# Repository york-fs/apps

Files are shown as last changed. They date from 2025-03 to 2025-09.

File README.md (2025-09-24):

# Accelerator Pedal Position Sensor (APPS)

A custom accelerator pedal position sensor built around an STM32F103 MCU for drive-by-wire and EV applications.  
This module measures pedal position using two SS49E Hall-effect sensors with independent, opposed magnets, provides a digital brake signal, and communicates throttle data directly to the inverter over CAN bus.

## Features
- **MCU**: STM32F103
- **Position sensing**:  
  - Two SS49E Hall-effect sensors  
  - Independent, opposed magnet configuration for rule compliance and redundancy 
- **Brake output**: Digital output line for brake LED / ECU input  
- **User controls**:  
  - Reset button  
  - Calibration button (pedal travel limits)
- **CAN transceiver**:  
  - Throttle data transmission  
  - Ready-to-drive state reporting  
  - Calibration / curve configuration



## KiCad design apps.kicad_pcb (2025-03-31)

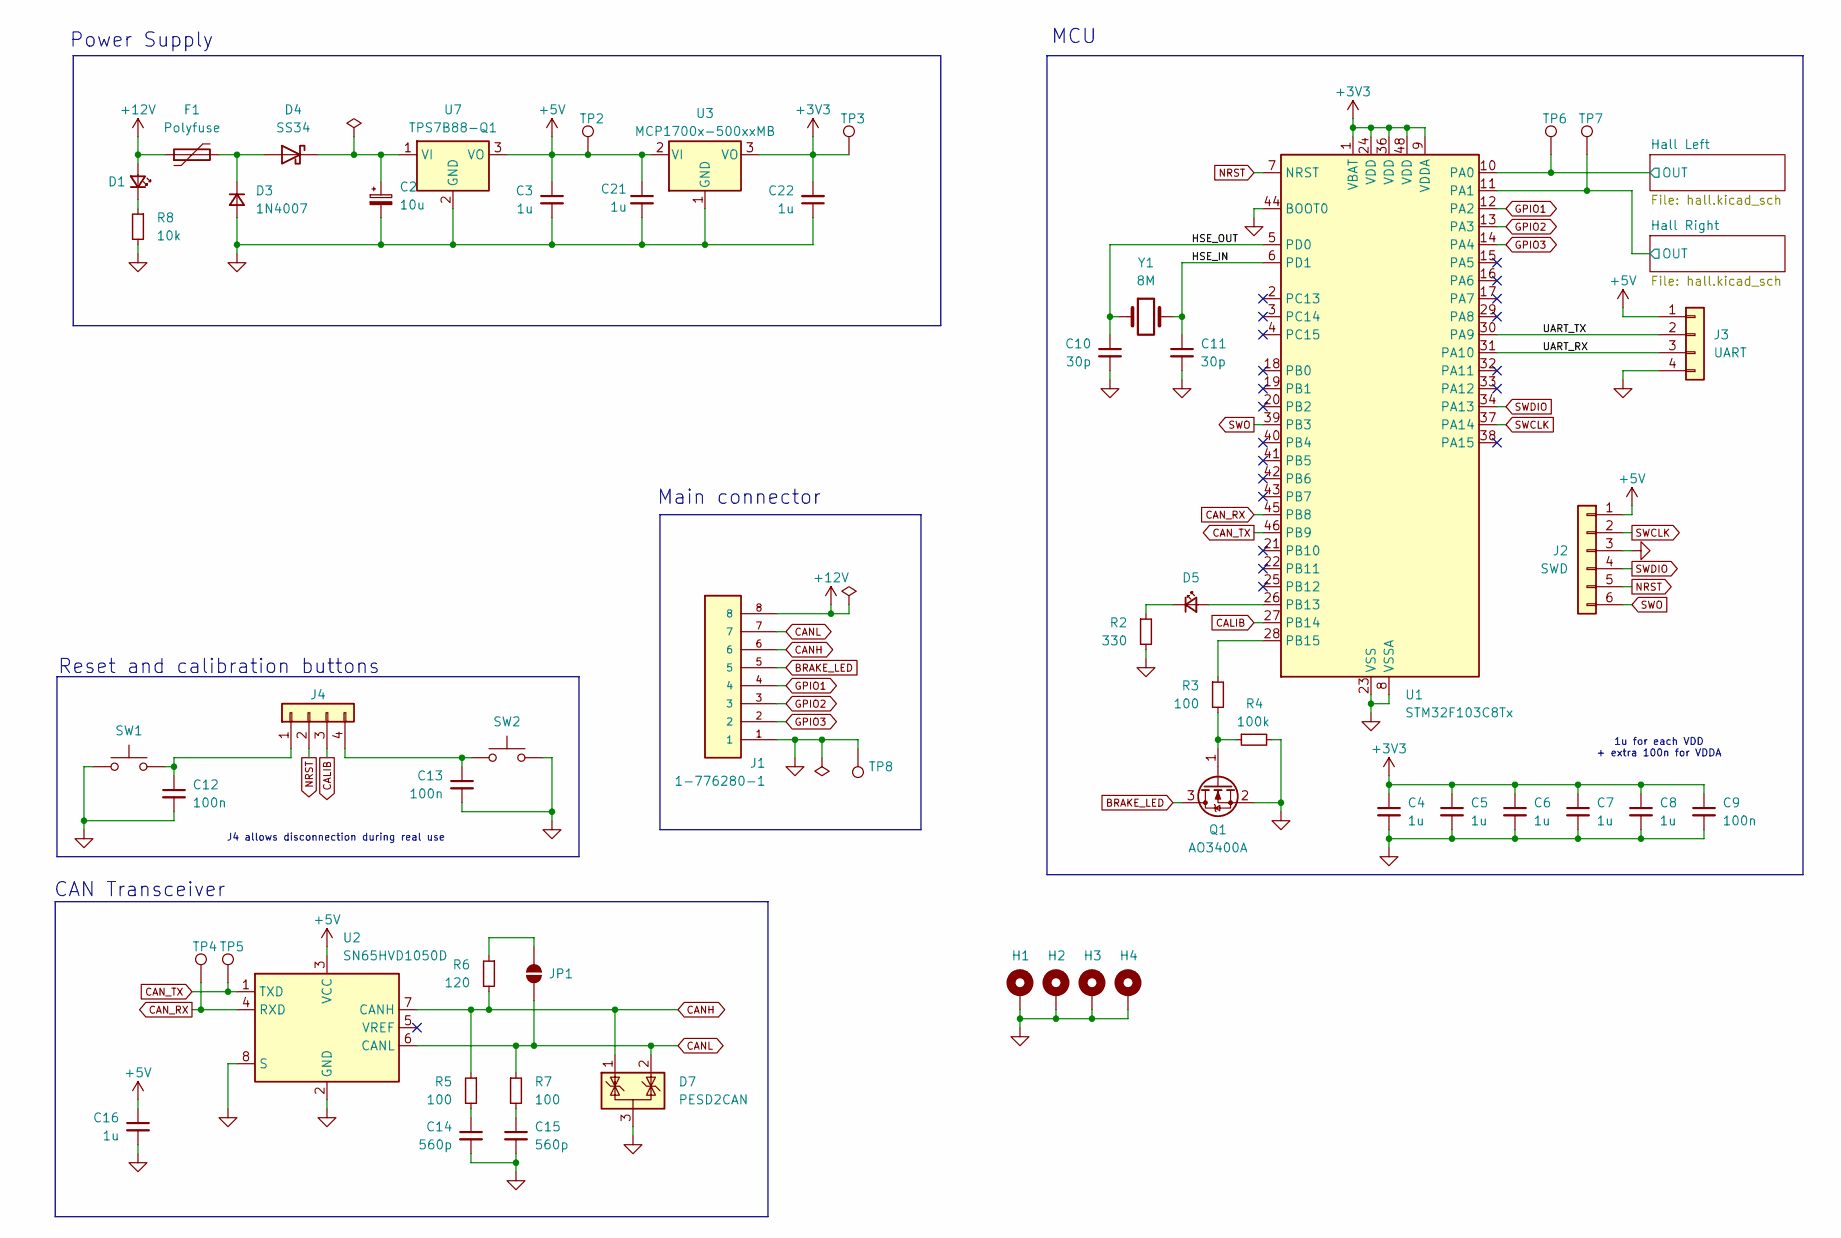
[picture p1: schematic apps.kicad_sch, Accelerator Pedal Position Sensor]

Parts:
C2: 10u; CP_Elec_6.3x5.4
C3, C4, C5, C6, C7, C8, C16, C21, C22: 1u; C_0603_1608Metric
C9, C12, C13: 100n; C_0603_1608Metric
C10, C11: 30p; C_0603_1608Metric
C14, C15: 560p; C_0603_1608Metric
D1, D5: LED_Small; LED_0603_1608Metric
D3: 1N4007; D_SOD-123F
D4: SS34; D_SMA
D7: PESD2CAN; SOT-23
F1: Polyfuse; R_0805_2012Metric
H1, H2, H3, H4: MountingHole_Pad; MountingHole_3.2mm_M3_Pad_Via
J1: 1-776280-1; TE_1-776280-1; PARTREV F8
J2: SWD; PinHeader_1x06_P2.54mm_Vertical
J3: UART; PinHeader_1x04_P2.54mm_Vertical
J4: Conn_01x04; PinHeader_1x04_P2.54mm_Vertical
JP1: SolderJumper_2_Open; SolderJumper-2_P1.3mm_Open_RoundedPad1.0x1.5mm
Q1: AO3400A; SOT-23
R2: 330; R_0603_1608Metric
R3, R5, R7: 100; R_0603_1608Metric
R4: 100k; R_0603_1608Metric
R6: 120; R_0603_1608Metric
R8: 10k; R_0603_1608Metric
SW1, SW2: SW_Push; SW_Push_SPST_NO_Alps_SKRK
TP2, TP3, TP4, TP5, TP6, TP7, TP8: TestPoint; TestPoint_Keystone_5000-5004_Miniature
U1: STM32F103C8Tx; LQFP-48_7x7mm_P0.5mm
U2: SN65HVD1050D; SOIC-8_3.9x4.9mm_P1.27mm
U3: MCP1700x-500xxMB; SOT-89-3
U7: TPS7B88-Q1; TO-252-2
Y1: 8M; Crystal_SMD_5032-2Pin_5.0x3.2mm

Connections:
+3V3: C4.1, C5.1, C6.1, C7.1, C8.1, C9.1, C22.2, TP3.1, U1.1 (VBAT), U1.9 (VDDA), U1.24 (VDD), U1.36 (VDD), U1.48 (VDD), U3.3 (VO); also elsewhere on the board
+5V: C3.1, C16.1, C21.1, J2.1, J3.1, TP2.1, U2.3 (VCC), U3.2 (VI), U7.3 (VO)
+12V: D1.2 (A), F1.1, J1.8
/HSE_IN: C11.1, U1.6 (PD1), Y1.2
/HSE_OUT: C10.1, U1.5 (PD0), Y1.1
/Hall Left/OUT: TP6.1, U1.10 (PA0); also elsewhere on the board
/Hall Right/OUT: TP7.1, U1.11 (PA1); also elsewhere on the board
/UART_RX: J3.3, U1.31 (PA10)
/UART_TX: J3.2, U1.30 (PA9)
BRAKE_LED: J1.5, Q1.3 (D)
CALIB: J4.3, U1.27 (PB14)
CANH: D7.1 (K), J1.6, R5.1, R6.2, U2.7 (CANH)
CANL: D7.2 (K), J1.7, JP1.2 (B), R7.1, U2.6 (CANL)
CAN_RX: TP4.1, U1.45 (PB8), U2.4 (RXD)
CAN_TX: TP5.1, U1.46 (PB9), U2.1 (TXD)
GND: C2.2, C3.2, C4.2, C5.2, C6.2, C7.2, C8.2, C9.2, C10.2, C11.2, C12.2, C13.2, C14.2, C15.2, C16.2, C21.2, C22.1, D3.2 (A), D7.3 (A), H1.1, H2.1, H3.1, H4.1, J1.1, J2.3, J3.4, Q1.2 (S), R2.2, R4.2, R8.2, SW1.1, SW2.1, TP8.1, U1.8 (VSSA), U1.23 (VSS), U1.35 (VSS), U1.44 (BOOT0), U1.47 (VSS), U2.2 (GND), U2.8 (S), U3.1 (GND), U7.2 (GND); also elsewhere on the board
GPIO1: J1.4, U1.12 (PA2)
GPIO2: J1.3, U1.13 (PA3)
GPIO3: J1.2, U1.14 (PA4)
NRST: J2.5, J4.2, U1.7 (NRST)
unnamed: C14.1, R5.2
unnamed: C15.1, R7.2
unnamed: D1.1 (K), R8.1
unnamed: D3.1 (K), D4.2 (A), F1.2
unnamed: C2.1, D4.1 (K), U7.1 (VI)
unnamed: D5.2 (A), U1.26 (PB13)
unnamed: D5.1 (K), R2.1
unnamed: C12.1, J4.1, SW1.2
unnamed: C13.1, J4.4, SW2.2
unnamed: JP1.1 (A), R6.1
unnamed: Q1.1 (G), R3.2, R4.1
unnamed: R3.1, U1.28 (PB15)
SWCLK: J2.2, U1.37 (PA14)
SWDIO: J2.4, U1.34 (PA13)
SWO: J2.6, U1.39 (PB3)

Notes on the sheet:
Power Supply
MCU
Reset and calibration buttons
1u for each VDD + extra 100n for VDDA
J4 allows disconnection during real use
CAN Transceiver
Main connector

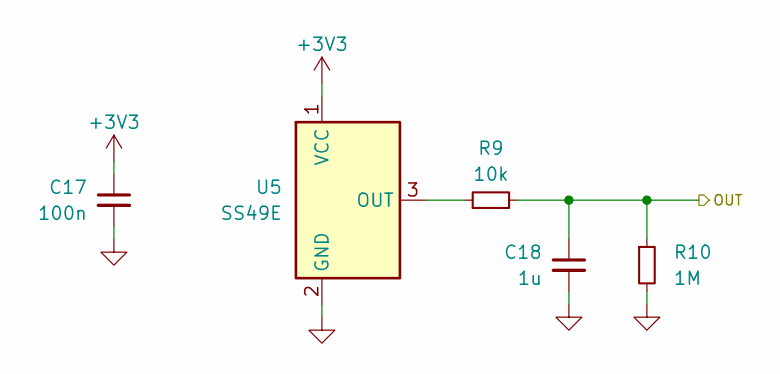
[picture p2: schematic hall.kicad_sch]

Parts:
C17: 100n; C_0603_1608Metric
C18: 1u; C_0603_1608Metric
R9: 10k; R_0603_1608Metric
R10: 1M; R_0603_1608Metric
U5: SS49E; SS49E_TO_92_Inline

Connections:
+3V3: C17.1, U5.1 (VCC); also elsewhere on the board
/Hall Left/OUT: C18.1, R9.2, R10.1; also elsewhere on the board
GND: C17.2, C18.2, R10.2, U5.2 (GND); also elsewhere on the board
unnamed: R9.1, U5.3 (OUT)

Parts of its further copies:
C19: 100n; C_0603_1608Metric
C20: 1u; C_0603_1608Metric
R11: 10k; R_0603_1608Metric
R12: 1M; R_0603_1608Metric
U6: SS49E; SS49E_TO_92_Inline

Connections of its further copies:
+3V3: C19.1, U6.1 (VCC); also elsewhere on the board
/Hall Right/OUT: C20.1, R11.2, R12.1; also elsewhere on the board
GND: C19.2, C20.2, R12.2, U6.2 (GND); also elsewhere on the board
unnamed: R11.1, U6.3 (OUT)

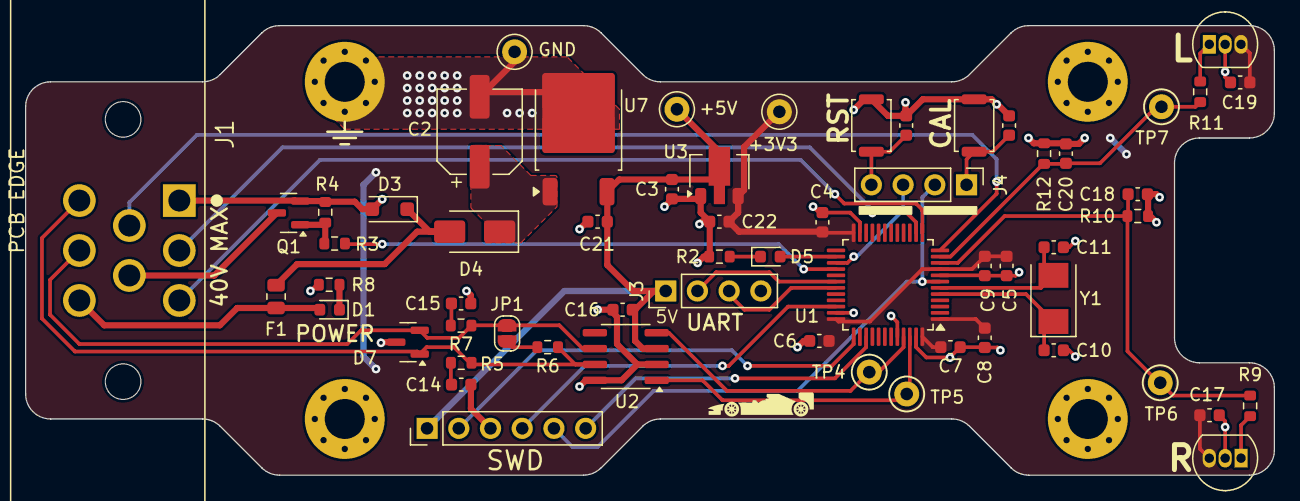
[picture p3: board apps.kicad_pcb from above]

Board: 2 copper layers, 100.0 x 36.0 mm, 64 parts (0 on the bottom side), 37 nets.

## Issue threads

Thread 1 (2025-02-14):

Wrong footprint for AMS voltage regulators

yeetari, 2025-02-14:

Closed 2025-04-09.

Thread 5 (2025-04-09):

Fix silkscreen labels around J3 (USART)

lansraad, 2025-04-09:

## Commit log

2025-01-30 schematic: Move C2 after D3
    [apps.kicad_sch]
2025-01-30 schematic: Add another ESD TVS diode to 12V input
    [apps.kicad_sch]
2025-01-31 schematic: Fix revision
    [apps.kicad_sch]
2025-01-31 schematic: Some changes
    * Add test points for hall sensors
    * Assign 2.54 mm header footprints
    * Fix CAN termination resistor
    [apps.kicad_sch, hall.kicad_sch]
2025-01-31 schematic: Add ESD TVS diodes for CAN bus
    [apps.kicad_sch]
2025-01-31 schematic: Assign footprints for 12 V diodes
    [apps.kicad_sch]
2025-02-03 schematic: Add symbol and footprint for main connector
    [apps.kicad_sch, hall.kicad_sch]
2025-02-03 pcb: Create first PCB revision
    [apps.kicad_pcb]
2025-03-31 Changed SS49E footprint and updated to KiCAD 9
    [apps.kicad_pcb, apps.kicad_sch, hall.kicad_sch]
2025-03-31 Updated CAN Transceiver and LDO
    [apps.kicad_pcb, apps.kicad_sch]
